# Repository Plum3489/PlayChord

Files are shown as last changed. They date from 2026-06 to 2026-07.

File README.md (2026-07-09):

# PlayChord - XIAO RP2040 MIDI Chord Controller
PlayChord is a USB MIDI chord controller built around the Seeed XIAO RP2040 microcontroller. It allows musicians and producers to play full chords with a single button press :]

### Key Features
- **7 Chord Buttons** - Play diatonic chords (I, ii, iii, IV, V, vi, vii°) in any key
- **Rotary Encoder** - Switch between 12 musical keys (C through B)
- **Chord Type Selection** - Toggle between Triads (3-note), 7th chords, and 9th chords
- **Octave Control** - Shift the entire chord range up/down by +-2 octaves
- **Major/Minor Mode** - Switch between Major and Natural Minor scales
- **OLED Display** - Display of current key, mode, and settings
- **USB MIDI** - Direct USB-C connection to DAW/music software



## Hardware Specification

### Bill of Materials (BOM)
| Qty | Item | Notes | Unit Price (USD) | Subtotal (USD) |
|----:|---|---|---:|---:|
| 1 | PCB (unsoldered) | PCB 1 | $5.00 | $5.00 |
| 1 | Seeed XIAO RP2040 | | $5.00 | $5.00 |
| 12 | Through-hole 1N4148 Diodes | | $0.03 | $0.36 |
| 11 | MX-Style switches | | $0.30 | $3.30 |
| 1 | EC11 Rotary Encoder | | $1.50 | $1.50 |
| 1 | 0.91" OLED Display | Pin order: **GND-VCC-SCL-SDA** (PCB must match) | $2.50 | $2.50 |
| 11 | White Blank DSA Keycaps | | $0.25 | $2.75 |
| 3 | M3×16 mm Screws | | $0.10 | $0.30 |
| 3 | M3×5×4 mm Heat-set Inserts | | $0.15 | $0.45 |
| | **Total** | | | **$21.16** |

### PCB Specifications
PCB Dimensions: 80mm × 91.835mm
Layer Count: 2 

pcb

schem

### Case Specifications
Outer Dimensions: 100mm × 111.84mm × 16.9mm

case

## Software Architecture

### Stack

- **Framework:** Arduino (PlatformIO compatible)
- **USB Communication:** Adafruit TinyUSB Library (MIDI over USB)
- **Display Driver:** Adafruit SSD1306 (I2C)
- **MIDI Library:** fortyseveneffects/MIDI Library v5.0.2

### How it works ^^

#### 1. **Matrix Scanning** (`scanMatrix()`)

Purpose: Read button states from 3×4 switch matrix
Method:  Row-by-row activation with column polling
Timing:  Scanned every 5ms in main loop

Process:
1. Set Row pin to LOW (activate)
2. Read all 4 Column pins (INPUT_PULLUP)
3. Debounce each switch (50ms delay)
4. Trigger press/release events
5. Set Row pin to HIGH (deactivate)
6. Move to next row

Rotary Encoder
Purpose: Change musical key via rotary encoder
Method:  Hardware interrupt on encoder Pin A
Timing:  Interrupt-driven (no polling)

Process:
1. Encoder Pin A triggers FALLING interrupt
2. Read Pin B to determine direction
3. Increment/Decrement encoderPos
4. Debounce: Ignore interrupts < 5ms apart
5. In main loop: Convert position delta to key change
6. Wrap around between C (0) and B (11)

Yeah!

##Chord Gen!!
Purpose: Convert button press -> MIDI note-on events
Input:   Chord index (0-6, representing I through vii°)

Process:
1. Select chord table (MAJOR_TRIADS or MINOR_TRIADS)
2. Calculate 3 base notes:
   - note = BASE_OCTAVE + currentKey + interval + (octaveShift × 12)
   - BASE_OCTAVE = 60 (C4 = middle C in MIDI)
   - currentKey = 0-11 (semitone offset)
   - interval = chord tone (0, 4, 7 for C Major triad)
   - octaveShift = -2 to +2 (user-controlled)
3. Send MIDI Note-On (velocity=100) for each note
4. Track active notes in activeNotes[128] array
5. If chordType ≥ 1: Add 7th tone
6. If chordType = 2: Add 9th tone

##Button functionality 
Button	    Mode	    Action
------------------------------
SW1-7	    Any	        Play diatonic chord I-vii°
SW8	    Release	     Octave shift +1 (max +2)
SW9	    Press	     Toggle chord type: Triad → 7th → 9th
SW10	    Release	     Octave shift -1 (min -2)
SW11	    Release      Toggle Major ↔ Minor mode
SW12	    Press	     PANIC: All notes off

# Flashing with PlatformIO
1. Open project folder in VS Code
2. Click PlatformIO Home icon (alien head)
3. Click "Open Project"
4. Select your project folder
5. Verify board is set to: seeed_xiao_rp2040
6. Connect XIAO RP2040 via USB-C
7. Click: PlatformIO -> Upload
8. Wait for "Upload successful"

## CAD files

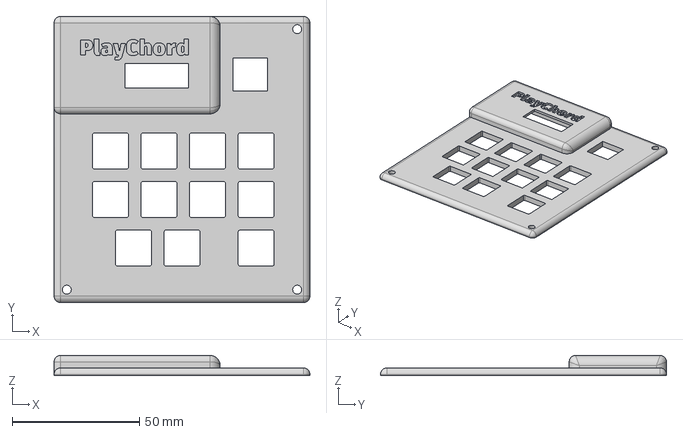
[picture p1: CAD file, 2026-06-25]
production/TOP.step
100.4 x 112.2 x 7.90 mm

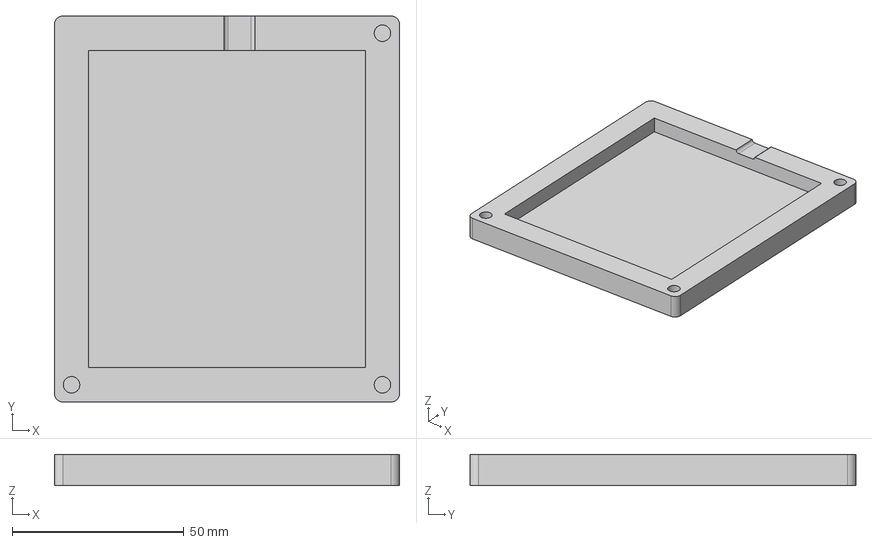
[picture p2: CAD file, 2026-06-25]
production/BOTTOM.step
100.4 x 112.2 x 9.11 mm

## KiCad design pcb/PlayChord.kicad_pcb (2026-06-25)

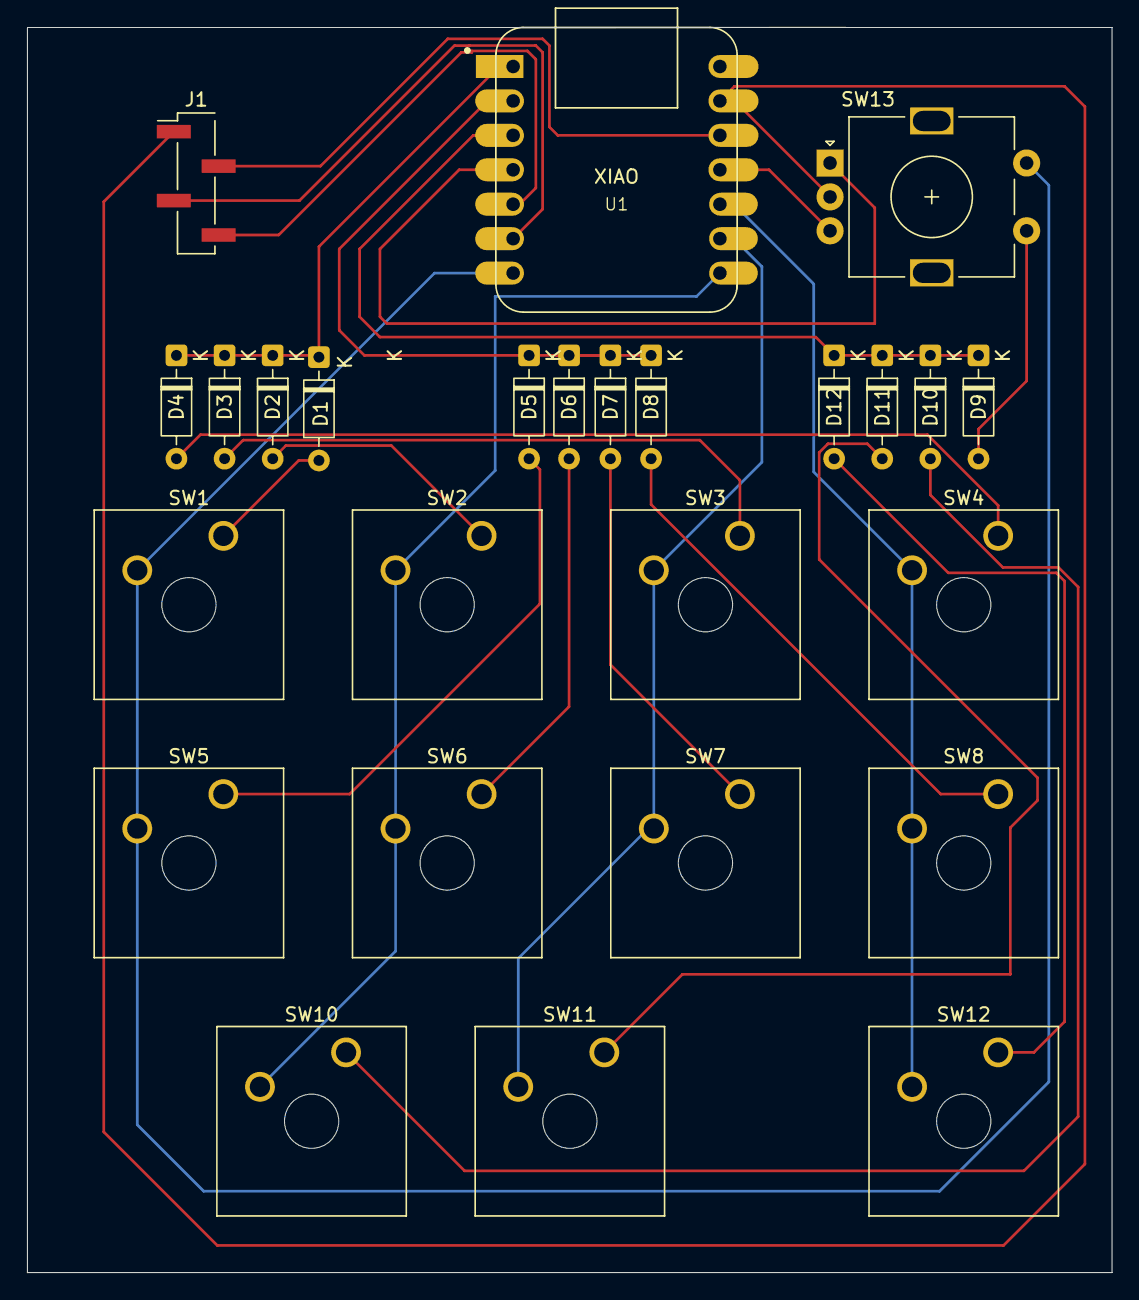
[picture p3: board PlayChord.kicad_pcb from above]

Board: 2 copper layers, 80.0 x 91.8 mm, 26 parts (0 on the bottom side), 25 nets.

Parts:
D1, D2, D3, D4, D5, D6, D7, D8, D9, D10, D11, D12: D_DO-35_SOD27_P7.62mm_Horizontal
J1: Conn_01x04_Pin; PinHeader_1x04_P2.54mm_Vertical_SMD_Pin1Left
SW1: I; SW_Cherry_MX_1.00u_Plate
SW2: II; SW_Cherry_MX_1.00u_Plate
SW3: III; SW_Cherry_MX_1.00u_Plate
SW4: IV; SW_Cherry_MX_1.00u_Plate
SW5: V; SW_Cherry_MX_1.00u_Plate
SW6: VI; SW_Cherry_MX_1.00u_Plate
SW7: VII; SW_Cherry_MX_1.00u_Plate
SW8: UP; SW_Cherry_MX_1.00u_Plate
SW10, SW11: SW_Cherry_MX_1.00u_Plate
SW12: DOWN; SW_Cherry_MX_1.00u_Plate
SW13: RotaryEncoder_Switch; RotaryEncoder_Alps_EC11E-Switch_Vertical_H20mm
U1: MOUDLE-SEEEDUINO-XIAO; XIAO-Generic-Hybrid-14P-2.54-21X17.8MM

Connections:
unnamed: D1.2 (A), SW1.1
unnamed: D1.1 (K), D2.1 (K), D3.1 (K), D4.1 (K), U1.1 (PA02_A0_D0)
unnamed: D2.2 (A), SW2.1
unnamed: D3.2 (A), SW3.1
unnamed: D4.2 (A), SW4.1
unnamed: D5.2 (A), SW5.1
unnamed: D5.1 (K), D6.1 (K), D7.1 (K), D8.1 (K), U1.2 (PA4_A1_D1)
unnamed: D6.2 (A), SW6.1
unnamed: D7.2 (A), SW7.1
unnamed: D8.2 (A), SW8.1
unnamed: D9.2 (A), SW13.S1
unnamed: D10.2 (A), SW10.1
unnamed: D9.1 (K), D10.1 (K), D11.1 (K), D12.1 (K), U1.3 (PA10_A2_D2)
unnamed: D11.2 (A), SW11.1
unnamed: D12.2 (A), SW12.1
unnamed: J1.1, SW13.C, U1.13 (GND)
unnamed: J1.2, U1.12 (3V3)
unnamed: J1.3, U1.6 (PA9_A5_D5_SCL)
unnamed: J1.4, U1.5 (PA8_A4_D4_SDA)
unnamed: SW4.2, SW8.2, SW12.2, U1.10 (PA5_A9_D9_MISO)
unnamed: SW13.B, U1.11 (PA6_A10_D10_MOSI)
unnamed: SW3.2, SW7.2, SW11.2, U1.9 (PA7_A8_D8_SCK)
unnamed: SW13.A, U1.4 (PA11_A3_D3)
unnamed: SW1.2, SW5.2, SW13.S2, U1.7 (PB08_A6_D6_TX)
unnamed: SW2.2, SW6.2, SW10.2, U1.8 (PB09_A7_D7_RX)

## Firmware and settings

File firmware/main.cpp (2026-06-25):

#include <Adafruit_TinyUSB.h>
#include <MIDI.h>
#include <Wire.h>
#include <Adafruit_GFX.h>
#include <Adafruit_SSD1306.h>

// Da Oled Display
#define SCREEN_WIDTH 128
#define SCREEN_HEIGHT 32
#define OLED_RESET -1
Adafruit_SSD1306 display(SCREEN_WIDTH, SCREEN_HEIGHT, &Wire, OLED_RESET);

const int SDA_PIN = D4;
const int SCL_PIN = D5;

// USB MIDI 
Adafruit_USBD_MIDI usb_midi;
MIDI_CREATE_INSTANCE(Adafruit_USBD_MIDI, usb_midi, MIDI);

// The Pins
const int ROW_PINS[3] = {D0,D1,D2};
const int COL_PINS[4] = {D6,D7,D8,D9};
const int ENCODER_A = D3;
const int ENCODER_B = D10;

// Mapping the button matrix
const int SWITCH_MAP[3][4]={
  {1,2,3,4}, // Row 0 => SW1-4
  {5,6,7,8}, // Row 1 => SW5-8
  {9,10,11,12} // ROW 2 => SW9-12
};

// debouncing input
bool buttonState[13] = {false};
bool lastButtonState[13] = {false};
unsigned long lastDebounceTime[13] = {0};
const unsigned long debounceDelay = 50;

// Rotary encoder
volatile int encoderPos = 0;
int lastEncoderPos = 0;
volatile unsigned long lastEncoderTime = 0;

// Music theory stuff
const char* KEY_NAMES[] = {"C", "Db", "D", "Eb", "E", "F", "Gb", "G", "Ab", "A", "Bb", "B"};
int currentKey = 0; // 0 = C, 1 = C# ergo for each halfstep +1
bool isMajor = true; // true => Major | false => minor
int octaveShift = 0; // -2 to +2 range
int chordType = 0; // 0=Triad, 1=Seventh, 2=Ninth

const int BASE_OCTAVE = 60; // C4 

// Defining the chords
const int MAJOR_TRIADS[7][3] = {
  {0,4,7}, // I: Majpor (C E G)
  {2,5,9}, // ii Minor (D-F-A)
  {4,7,11}, // iii: Minor (E G B)
  {5,9,12}, // IV: Major (F A C)
  {7,11,14}, // V: Major (G B D)
  {9,12,16}, // vi: Moll (A C E)
  {11,14,17} // vii°: aug (B D F)
};

const int MINOR_TRIADS[7][3] = {
  {0,3,7}, // i: Minor (C Eb G)
  {2,5,8}, // ii°: aug (D F Ab)
  {3,7,10}, // III: Major (Eb G Bb)
  {5,8,12}, // iv: Minor (F Ab C)
  {7,10,14}, // v: Minor (G Bb D)
  {8,12,15}, // VI: Major (Ab C Eb)
  {10,14,17} // VII: Major (Bb D F)
};

// Seventh
const int SEVENTH_INTERVALS[7] = {11,12,14,16,17,19,21};

// Ninth
const int NINTH_INTERVALS[7] = {14,14,16,17,19,21,21};

// Track active notes
bool activeNotes[128] = {false};

void updateDisplay();
void scanMatrix();
void checkEncoder();
void handleButtonPress(int sw);
void handleButtonRelease(int sw);
void playChord(int chordIndex);
void stopChord(int chordIndex);
void stopAllNotes();

// Interrupt when rotary encoder
void encoderISR(){
  unsigned long currentTime = millis();

  // Debounce
  if (currentTime - lastEncoderTime > 5){
    if(digitalRead((ENCODER_B) == HIGH)){
      encoderPos++;
    }else{
      encoderPos--;
    }
    lastEncoderTime = currentTime;
  }
}

void setup(){
  Serial.begin(115200);

  // Wait for serial (for debugging lol)
  // while (!Serial) delay(10);

  Serial.println("XIAO RP2040 Chord Midi Keyboard: PlayChord :P");

  // init USB midi
  usb_midi.setStringDescriptor("PlayChord");

 
  Wire.setSDA(SDA_PIN);
  Wire.setSCL(SCL_PIN);
  Wire.begin();
  
  if(!display.begin(SSD1306_SWITCHCAPVCC, 0x3C)) {
    Serial.println(F("OLED init failed!"));
  } else {
    Serial.println("OLED initialized");
  }

  // Splash
  display.clearDisplay();
  display.setTextSize(1);
  display.setTextColor(SSD1306_WHITE);
  display.setCursor(0,0);
  display.println("PlayChord v1.0");
  display.println("XIAO RP2040");
  display.println("Initializing... :3");
  display.display();
  delay(1500);

  // Setup matrix
  for (int i = 0; i<3; i++){
    pinMode(ROW_PINS[i], OUTPUT),
    digitalWrite(ROW_PINS[i], HIGH);
  }
  for(int i = 0; i<4; i++){
    pinMode(COL_PINS[i], INPUT_PULLUP);
  }

  // Rotary encoder setup
  pinMode(ENCODER_A, INPUT_PULLUP);
  pinMode(ENCODER_B, INPUT_PULLUP);

  // Interrupt 
  attachInterrupt(digitalPinToInterrupt(ENCODER_A), encoderISR, FALLING);

  // start midi
  MIDI.begin(MIDI_CHANNEL_OMNI);

  Serial.println("Setup complete! :P");
  Serial.println("Waiting for USB Midi connection ...");

  updateDisplay();

  
}

void loop(){
  // Scan Matrix
  scanMatrix();

  // Checking da encoder
  checkEncoder();

  static unsigned long lastDisplayUpdate = 0;
  if(millis() - lastDisplayUpdate > 100){
    updateDisplay();
    lastDisplayUpdate = millis();
  }

  delay(5);
}

void scanMatrix(){
  for(int row = 0; row < 3 ; row ++){
    // Activate Row, put on LOW
    digitalWrite(ROW_PINS[row], LOW);
    delayMicroseconds(10);

    // Read all Columns in the row
    for (int col = 0; col<4; col++){
      int switchNum = SWITCH_MAP[row][col];
      bool reading = !digitalRead(COL_PINS[col]);
      
      // Debounce
      if(reading != lastButtonState[switchNum]){
        lastDebounceTime[switchNum] = millis();

      }

      if((millis() - lastDebounceTime[switchNum])> debounceDelay){
        if(reading != buttonState[switchNum]){
          buttonState[switchNum] = reading;

          if(reading){
            handleButtonPress(switchNum);
          }else{
            handleButtonRelease(switchNum);
          }
        
        }
        
      }
      lastButtonState[switchNum] = reading;
    }

    // Deactivate row
    digitalWrite(ROW_PINS[row], HIGH);


  }
}

void handleButtonPress(int sw){
  Serial.print("Button ");
  Serial.print(sw);
  Serial.println(" pressed");

  if(sw>=1 && sw <= 7){
    playChord(sw-1);
  }
  else if(sw==8){
    //SW8: Ocatve Up
    if(octaveShift <2){
      octaveShift++;
      stopAllNotes();
      Serial.print("Pctave shift: ");
      Serial.println(octaveShift);
    }
  }
  else if(sw == 9){
    // SW9 (Encoder button): switch chordtype
    chordType = (chordType +1)%3;
    stopAllNotes();
    Serial.print("Chord type: ");
    Serial.println(chordType == 0 ? "Triad" : (chordType == 1 ? "7th" : "9th"));

  }
   else if (sw == 10) {
    // SW10: octave down
    if (octaveShift > -2) {
      octaveShift--;
      stopAllNotes();
      Serial.print("Octave shift: ");
      Serial.println(octaveShift);
    }
  } 
  else if (sw == 11) {
    // SW11: Major/Minor 
    isMajor = !isMajor;
    stopAllNotes();
    Serial.println(isMajor ? "Major" : "Minor");
  } 
  else if (sw == 12) {
    // SW12: Panic Button all off
    stopAllNotes();
    Serial.println("PANIC - All notes off");
  }
}

void handleButtonRelease(int sw){
  if(sw >= 1 && sw <= 7){
    // Stop the chord
    stopChord(sw -1);
  }
}

void playChord(int chordIndex){
  // choose the right chord from the table
  const int (*triads)[3] = isMajor ? MAJOR_TRIADS : MINOR_TRIADS;

  Serial.print("Playing chord: ");
  Serial.print(chordIndex +1);
  Serial.print(" in ");
  Serial.print(KEY_NAMES[currentKey]);
  Serial.println(isMajor ? " Major" : " Minor");

  // Play the notes for the triad
  for (int i = 0; i < 3; i++) {
    int note = BASE_OCTAVE + currentKey + triads[chordIndex][i] + (octaveShift * 12);
    
    if (note >= 0 && note < 128) {
      MIDI.sendNoteOn(note, 100, 1);
      activeNotes[note] = true;
      Serial.print("  Note ON: ");
      Serial.println(note);
    }
  }
  
  // Add the 7th
  if (chordType >= 1) {
    int note = BASE_OCTAVE + currentKey + SEVENTH_INTERVALS[chordIndex] + (octaveShift * 12);
    
    if (note >= 0 && note < 128) {
      MIDI.sendNoteOn(note, 100, 1);
      activeNotes[note] = true;
      Serial.print("  7th ON: ");
      Serial.println(note);
    }
  }
  
  // Add the 9th
  if (chordType == 2) {
    int note = BASE_OCTAVE + currentKey + NINTH_INTERVALS[chordIndex] + (octaveShift * 12);
    
    if (note >= 0 && note < 128) {
      MIDI.sendNoteOn(note, 90, 1);
      activeNotes[note] = true;
      Serial.print("  9th ON: ");
      Serial.println(note);
    }
  }
}

void stopChord(int chordIndex){
  // Stop all active notes
  for(int i = 0; i < 128; i++){
    if(activeNotes[i]){
      MIDI.sendNoteOff(i,0,1);
      activeNotes[i] = false;
    }
  }
}

void stopAllNotes(){
  // Panic aahhh
  for(int i = 0; i<128; i++){
    if(activeNotes[i]){
      MIDI.sendNoteOff(i,0,1);
      activeNotes[i] = false;
    }
  }
}

void checkEncoder(){
  if(encoderPos != lastEncoderPos){
    int diff = encoderPos - lastEncoderPos;
    currentKey += diff;

    // wrap around between i (0) and B(11)
    while(currentKey < 0) currentKey += 12;
    while(currentKey >= 12) currentKey -= 12;

    lastEncoderPos = encoderPos;
    stopAllNotes();

    Serial.print("Key changed to: ");
    Serial.println(KEY_NAMES[currentKey]);
  }
}

void updateDisplay(){
  display.clearDisplay();

  // ln 1 Key, large
  display.setCursor(0,0);
  display.print(KEY_NAMES[currentKey]);
  display.print(" ");
  display.print(isMajor ? "Maj" : "Min");

  // ln 2 Octave and Type
  display.setTextSize(1);
  display.setCursor(0,18);
  display.print("Oct: ");
  if(octaveShift>=0){display.print("+");}
  display.print(octaveShift);

  display.setCursor(60,18);
  display.print("Type: ");
  if (chordType == 0) display.print("3");
  else if (chordType == 1) display.print("7");
  else display.print("9");
  
  // ln 3 Status
  display.setCursor(0, 26);
  display.print("USB MIDI Ready");
  
  display.display();

}
